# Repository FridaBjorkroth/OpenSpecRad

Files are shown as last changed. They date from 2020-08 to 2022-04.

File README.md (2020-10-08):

# The OpenSpecRad system
This is the repository for files created during the development of an Open-source SpectroRadiometer (OpenSpecRad) system. The OpenSpecRad system is used for in situ measurement of the water-leaving reflectance, used in water quality monitoring of marine and lake water. All software and drawings are available and open-source, which means that anyone can download and use and/or make changes to the construction.

The water-leaving radiance is the spectrum of sunlight backscattered out of the ocean after interaction with the water and its constituents. Each component, as well as the water itself, has different inherent optical properties (IOPs) and absorbs and scatters different parts of the spectrum. Therefore the water-leaving radiance holds quantitative and qualitative information about the main optically active components of water, i.e. chlorophyll-a (Chl-a), coloured dissolved organic
matter (CDOM), and total suspended matter (TSM). Through bio-optical algorithms their concentrations can be derived.

## Using the OpenSpecRad system 
The downwelling irradiance Ed(z,λ) and upwelling radiance Lu(z,λ) is measured using an in-water instrument (Pic), as well as the downwelling irradiance just above the sea surface Ed(0+,λ) using a separate unit. The in-water instrument was built from two 3D-printed pressure and waterproof housings mounted onto a custom steel frame. The above-water unit was put in a plastic box to make it splash-proof. The measurement is started remotely by connecting a laptop/smartphone to the local WiFi network managed by the above-water unit. 

## Hardware
The hardware was based on the STS Developer's Kit from Ocean Optics (now Ocean Insight). The in-water units each include a STS-VIS miniature spectrometer, a Raspberry Pi 3B+ single-board computer, a Bar30 pressure sensor from Blue Robotics coupled via an I²C level converter, and a 10 Ah battery. The above-water unit was configured in the same way, except for the pressure sensor that was swapped for a real-time clock (RTC).

## Software
The open-source spectrometer device driver library SeaBreeze (version 3.0.11, Ocean Optics) was used for communicating with the spectrometers. A C program was written for making spectral measurements. A shell program was then developed for controlling the OpenSpecRad system from a laptop, e.g. starting the measurement programs, detecting errors, and transferring the collected data remotely via SSH. The measurement parameters, e.g. integration time, minimum depth for the first measurement, and depth resolution, were read from separate files when starting the three radiometric acquisitions, making changes of parameters easy.





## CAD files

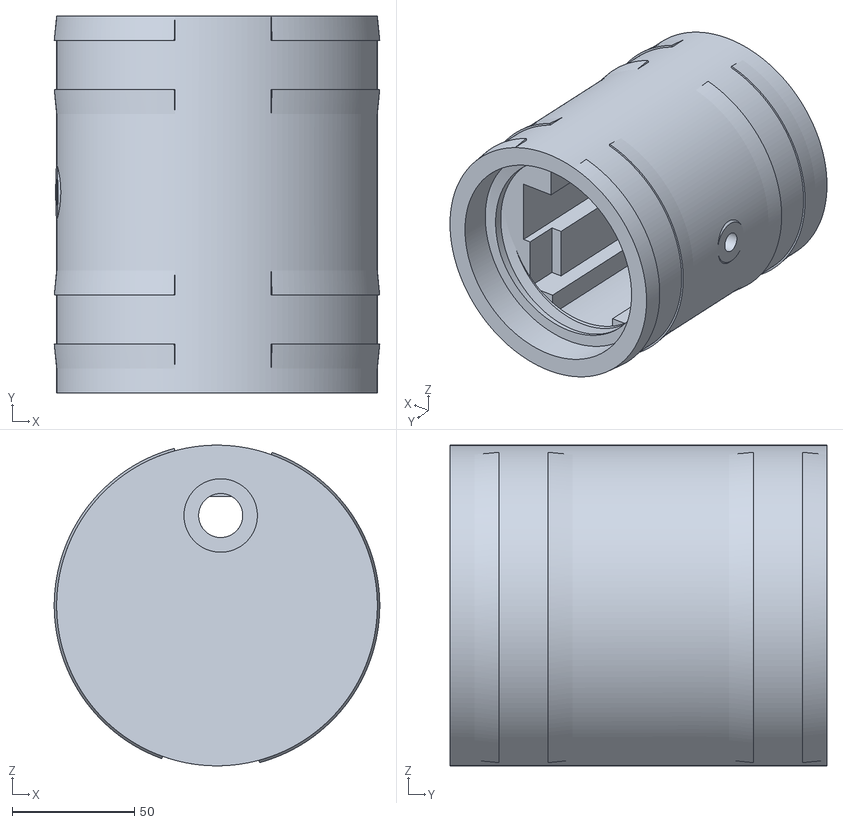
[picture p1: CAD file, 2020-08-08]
Housing and frame/Housing_11052020.stl
133.0 x 154.0 x 131.0

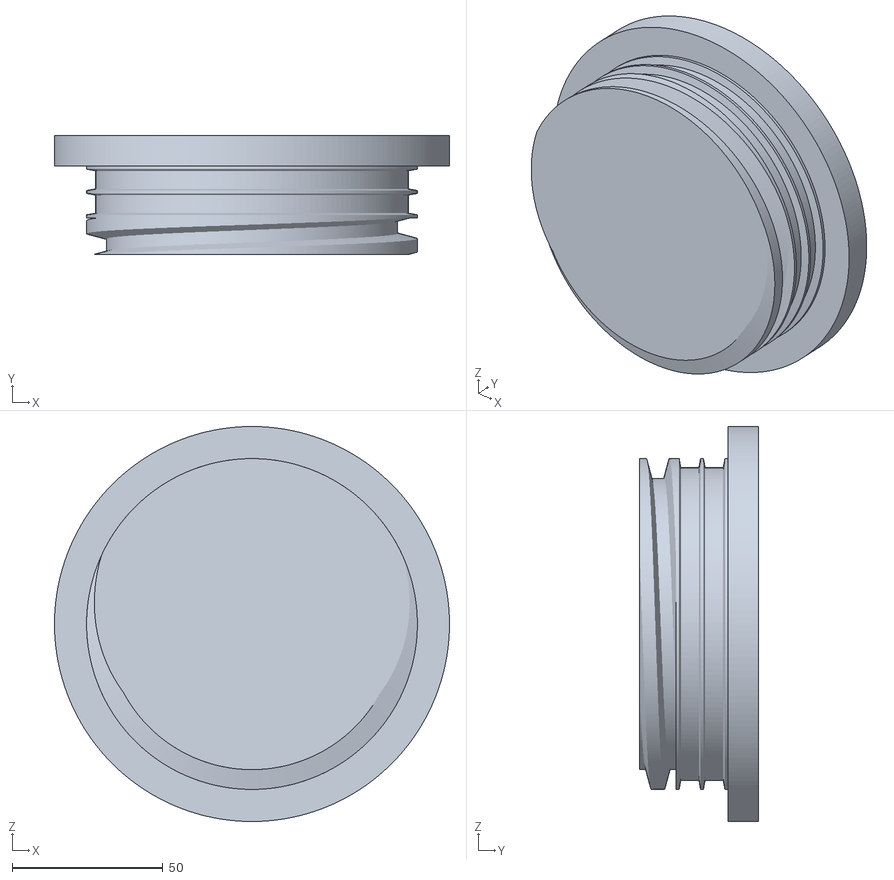
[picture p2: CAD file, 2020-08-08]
Housing and frame/Lid_11052020.stl
131.0 x 39.3 x 131.0

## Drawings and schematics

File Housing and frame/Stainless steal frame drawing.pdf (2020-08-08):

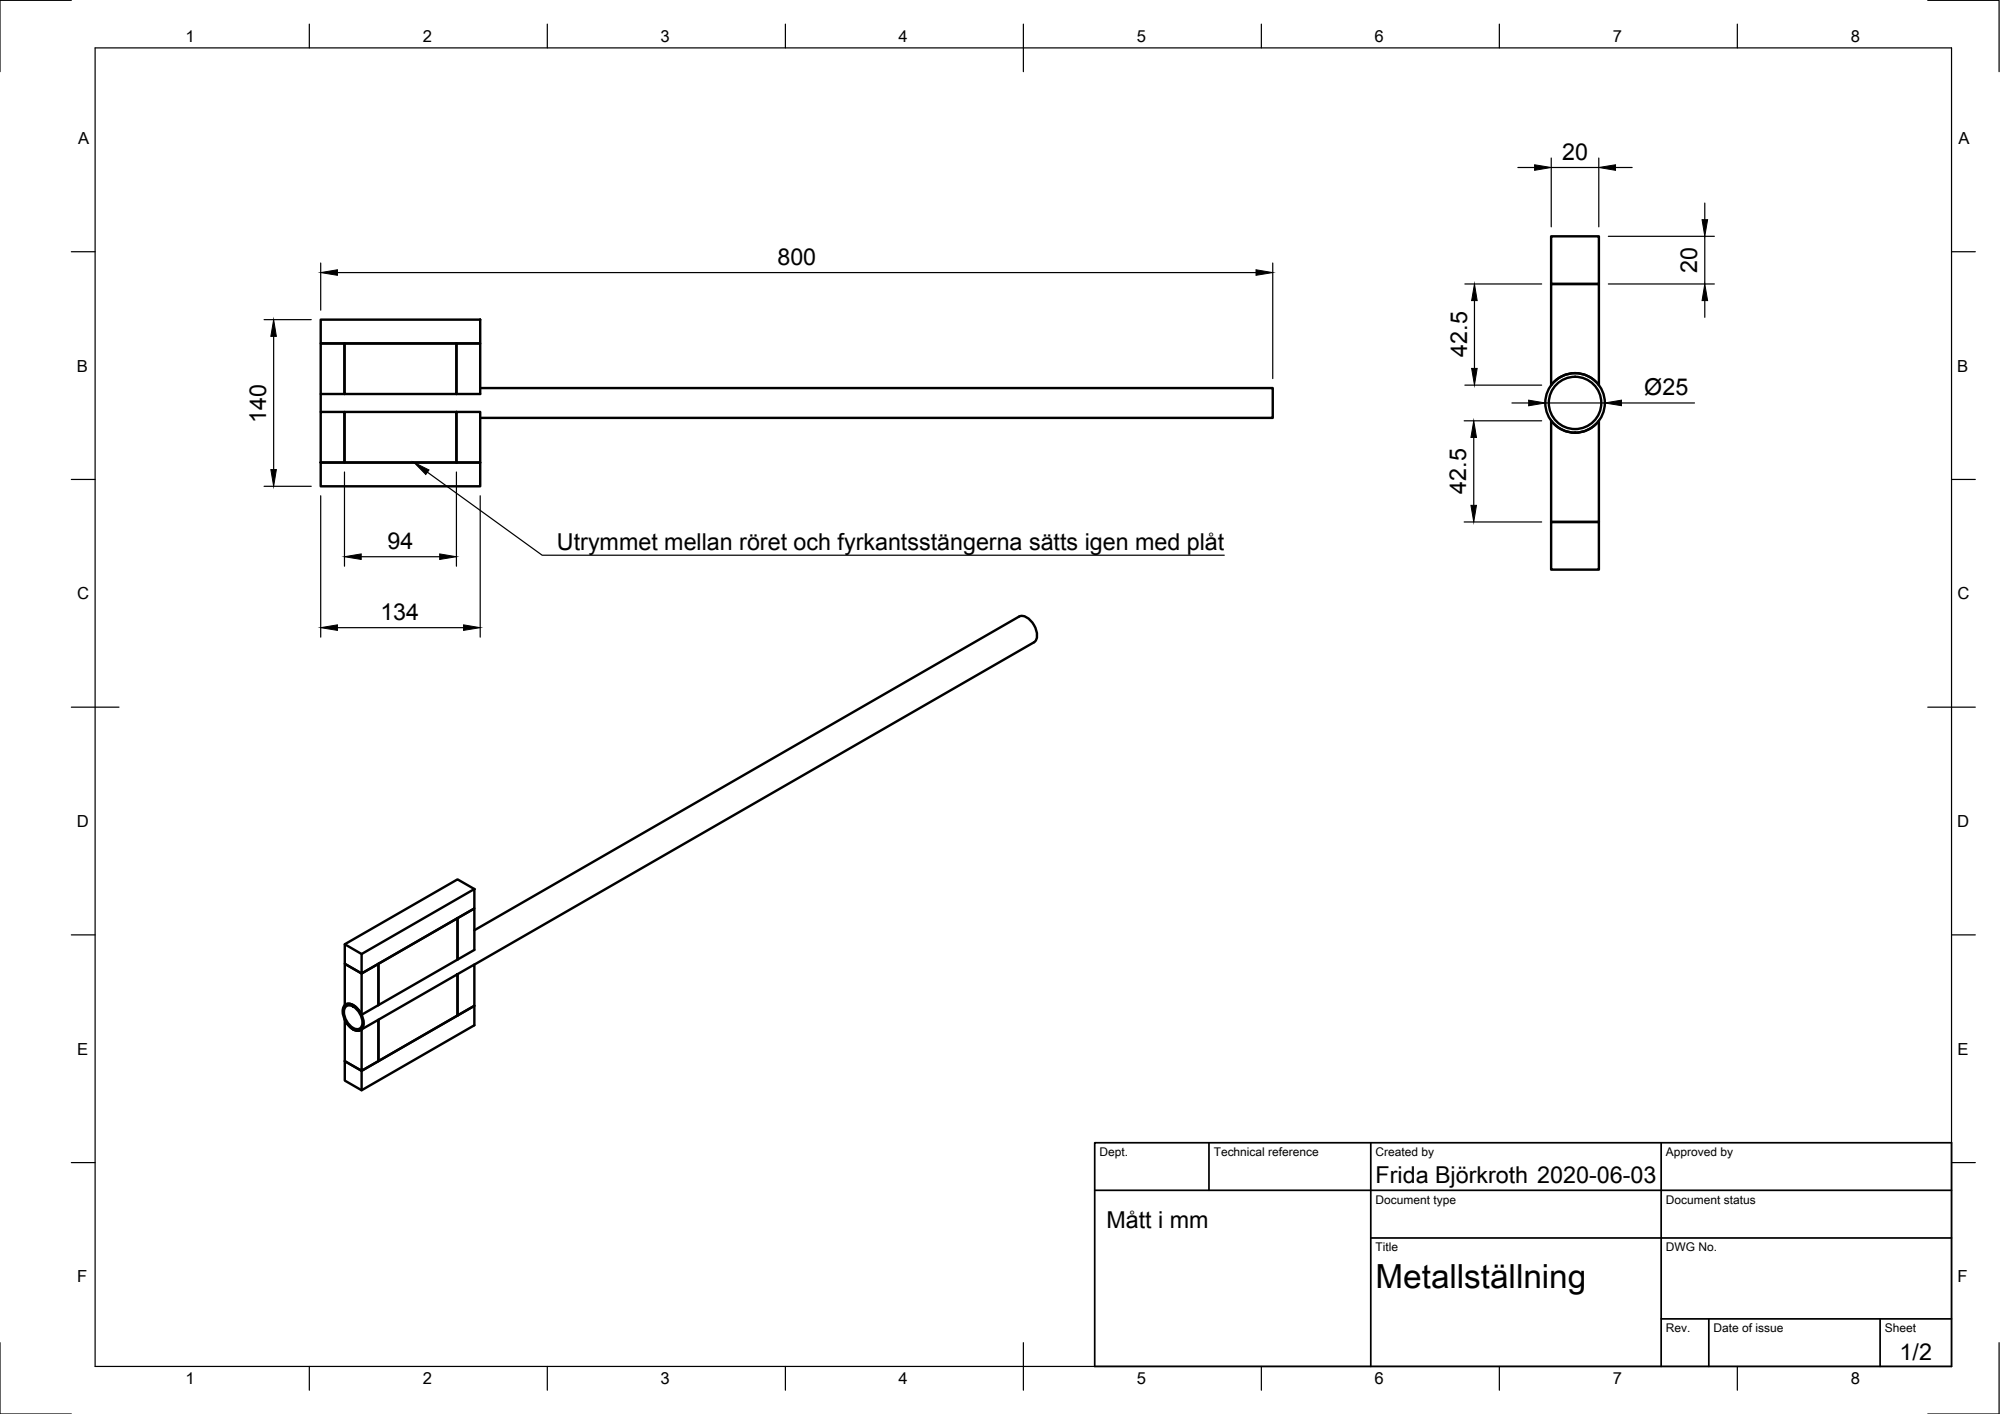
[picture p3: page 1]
Frida Björkroth; Utrymmet mellan röret och fyrkantsstängerna sätts igen med plåt

Dept. | Technical reference | Created by 2020-06-03 | Approved by

Mått i mm | | Document type | Document status

Title Metallställning | DWG No.

Rev. | Date of issue | Sheet 1/2

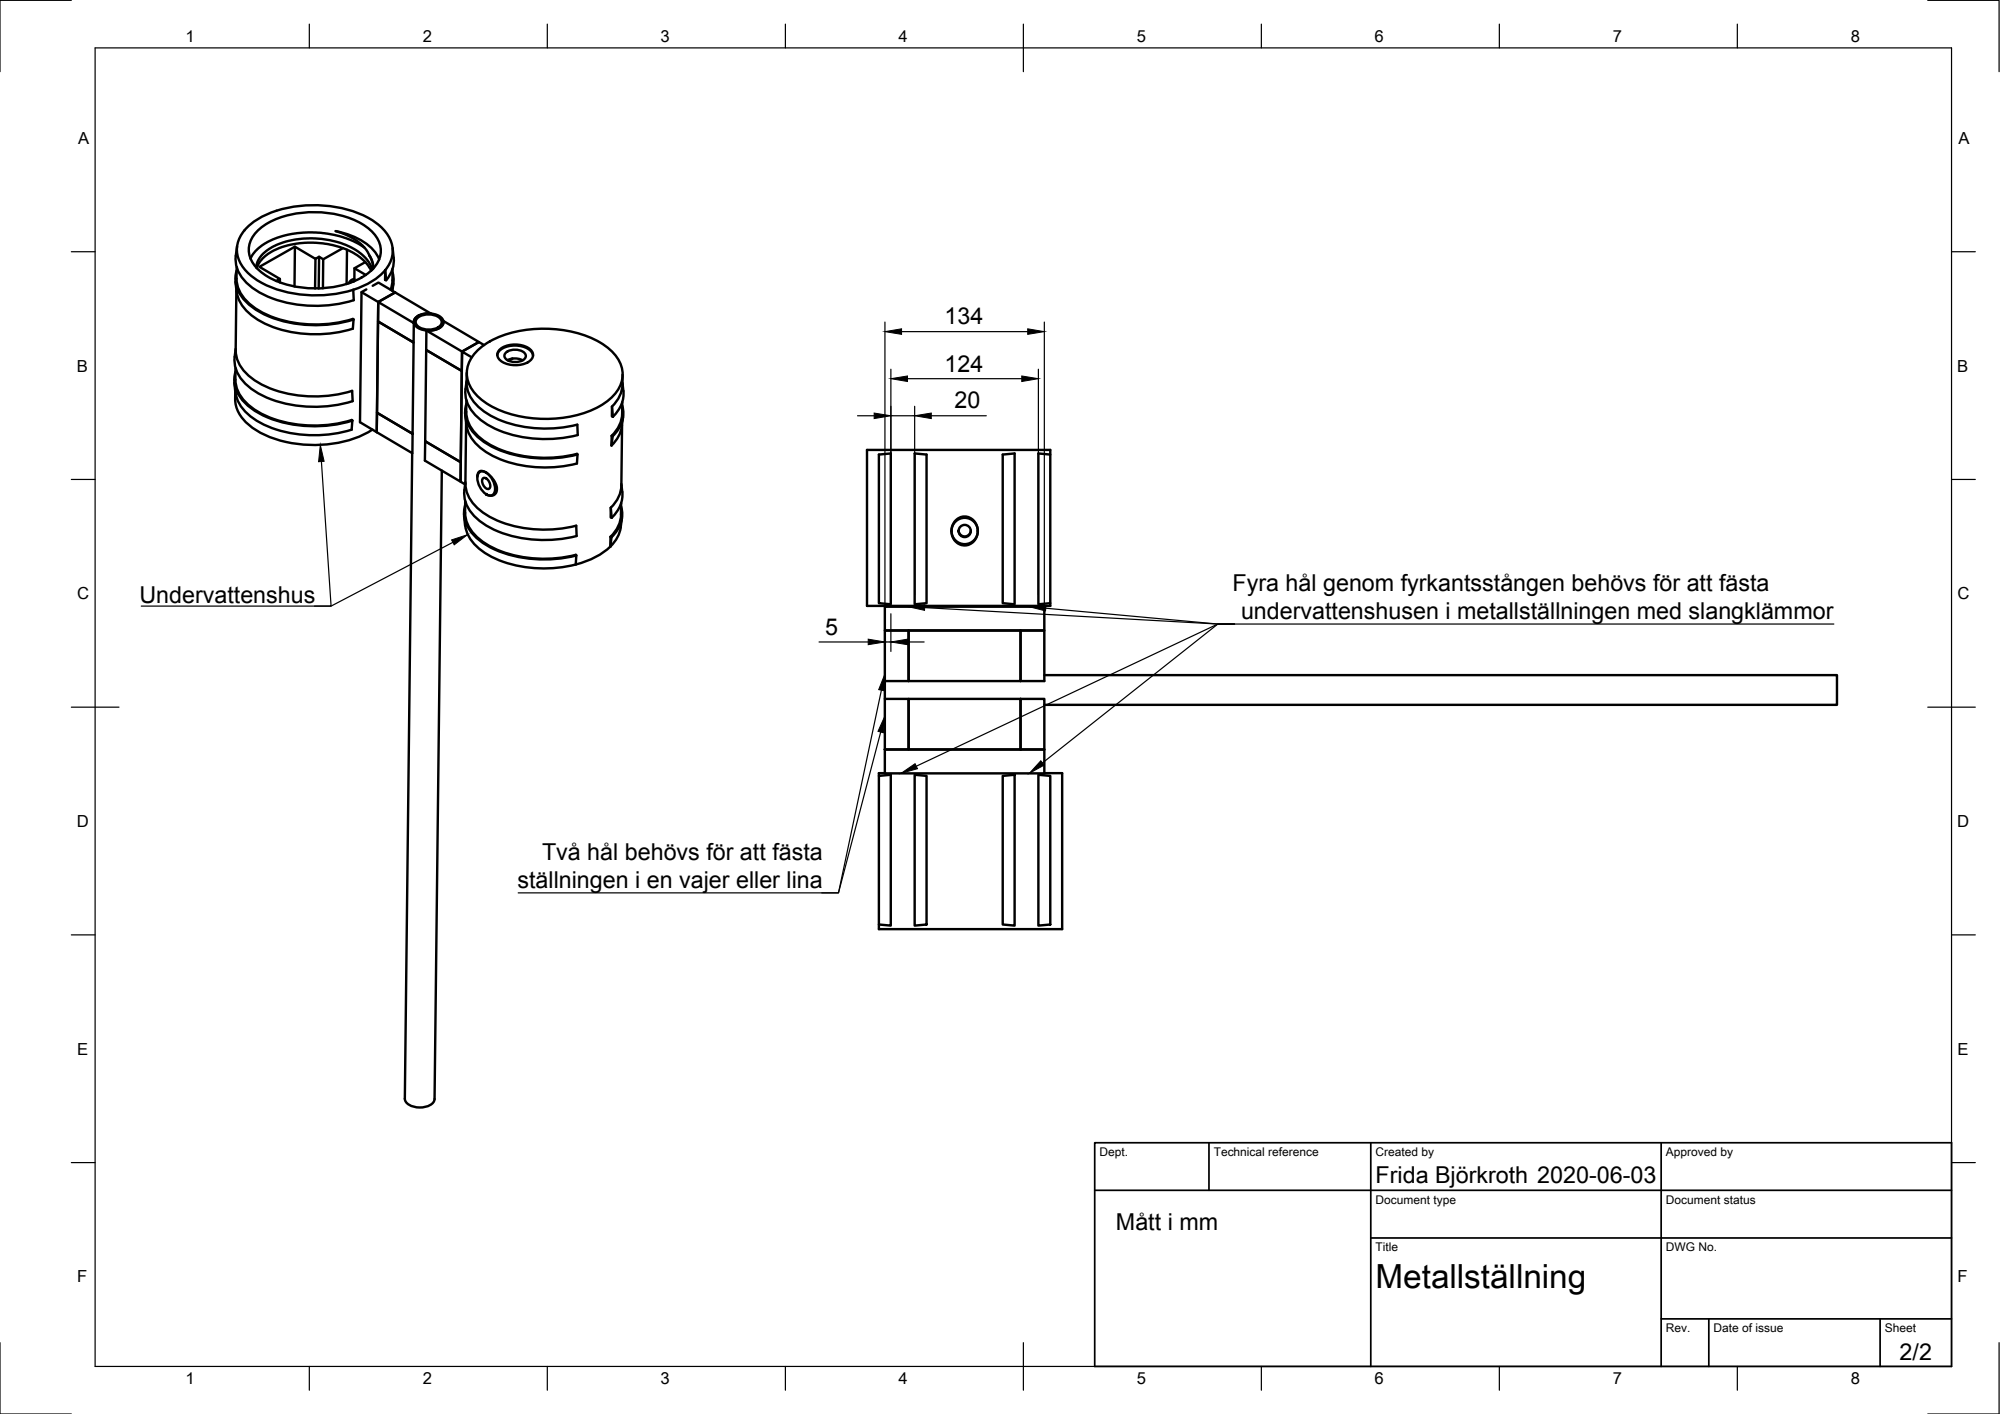
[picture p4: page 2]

Fyra hål genom fyrkantsstången behövs för att fästa

undervattenshusen i metallställningen med slangklämmor Undervattenshus

Två hål behövs för att fästa
ställningen i en vajer eller lina

Dept. | Technical reference | Created by Frida Björkroth 2020-06-03 | Approved by

Mått i mm | | Document type | Document status

Title Metallställning | DWG No.

Rev. | Date of issue | Sheet 2/2

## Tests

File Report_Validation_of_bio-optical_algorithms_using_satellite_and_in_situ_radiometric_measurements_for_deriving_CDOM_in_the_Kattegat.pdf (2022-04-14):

## DEPARTMENT OF MARINE SCIENCES

# VALIDATION OF BIO-OPTICAL ALGORITHMS USING SATELLITE AND IN SITU RADIOMETRIC MEASUREMENTS FOR DERIVING COLOURED DISSOLVED ORGANIC MATTER (CDOM) IN THE KATTEGAT

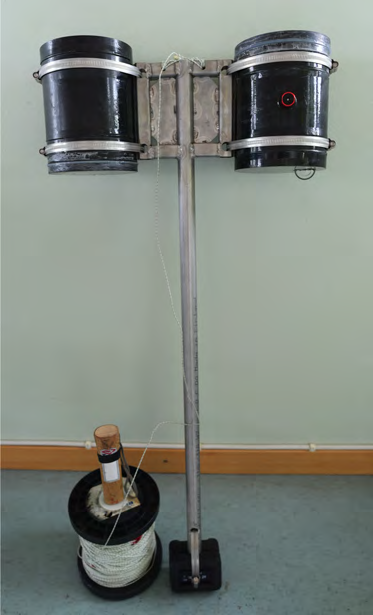
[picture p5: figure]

Figure 1: The in-water instrument, part of the

in situ Open-source SpectroRadiometer (Open-

SpecRad) system.

Frida Björkroth

Degree project for Master of Science (120 hp) with a major in Marine Sciences MAR703, Exam course for Master’s degree in Marine Science - Chemistry, 60 hp Second Cycle
Semester/year: Spring 2020
Supervisor: Martin Hassellöv, Department of Marine Sciences
Examiner: Katarina Abrahamsson, Department of Marine Sciences

## Validering av bio-optiska algoritmer för beräkning av

## humusämnen i Kattegatt

Satellitbaserad fjärranalys av havsfärg innebär att mäta solljuset som spridits tillbaka upp från

havsvattnet efter att ha interagerat med vattnet och dess innehåll. De huvudsakliga optiskt

aktiva beståndsdelarna, klorofyll-a, humusämnen och lösta partiklar, har olika egenskaper

som påverkar vilka färger (våglängder) av ljuset som absorberas eller sprids. Därför innehåller

ljuset information om mängd och om vilka av beståndsdelarna som finns där. Intresset för

humusämnen har nyligen ökat, eftersom man vill uppskatta det globalt lösta kolet i havet för

bättre förståelse av kolcykeln. Mätning av löst kol är tidskrävande och kostsamt, så därför

kan humusämnen användas för att uppskatta kolmängden. Humusämnen absorberar blått ljus

och ser därför gula ut i vatten. Genom bio-optiska algoritmer, som kopplar ihop biologiska

och optiska egenskaper, kan mängden av beståndsdelarna beräknas från satellitmätningar av

ljuset. De globala algoritmerna som används idag fungerar bra i optiskt enkla vatten, där

klorofyll-a dominerar, men misslyckas i optiskt komplicerade vatten, där humusämnen och

lösta partiklar dominerar. Därför har enkla regionala algoritmer som baseras på förhållandet

mellan två olika våglängdsband utvecklats.

En av de senaste sensorerna för fjärranalys av havsfärg är Ocean and Land Color Instrument

(OLCI) ombord på satelliterna Sentinel-3A och 3B. Dess våglängdsband är speciellt utvalda för

övervakning av optiskt komplicerade kustvatten. Validering och uppskattning av osäkerheter

från olika vattenmiljöer är avgörande för tillförlitlig data från OLCI. Detta görs genom

jämförelse mellan sammanfallande satellitmätningar och mätningar på plats i eller precis

ovanför vattnet. Dock har aldrig ljusmätningarna från OLCI med fokus på humusämnen

validerats omfattande i Kattegatt. Därför jämfördes mätningar av humusämnen på plats

i Kattegatt med lokalt anpassade algoritmer applicerade på mätningar från ett egenbyggt

optiskt instrument (Open-source SpectroRadiometer system, OpenSpecRad) och OLCI satel-

litmätningar. Resultaten visar att mängden humusämnen förutspått av algoritmerna inte

hade något förhållande till den verkliga mängden humusämnen, på grund av stor tidsskillnad

mellan satellitmätning och mätning på plats i lokala anpassningen av algoritmerna, orsakat

av molntäcke. För första gången visas det att OLCI-dataprodukten för färgat detritus och

löst material, ADG443, inte hade något förhållande till mätningar av humusämnen på plats.

Molntäcken är den största svagheten med satellitbaserad fjärranalys i Kattegatt, liksom

i resten av norra Europa. ADG443 rekommenderas inte att användas för att uppskatta

mängden humusämnen i Kattegatt. I framtiden skulle satellitbaserad fjärranalys av havsfärg

kunna öka tillgängligheten av mätningar av humusämnen och användas i övervakning av

vattenkvalitet. OpenSpecRad är billig och fritt tillgänglig för vem som helst att bygga, vilket

utmanar gränserna för vem som kan bidra till vetenskapen.

## Abstract

Satellite remote sensing of ocean color involves deriving the water-leaving radiance (Lw), which

is the spectrum of sunlight backscattered out of the ocean after interaction with the water

and its constituents. The Lw holds quantitative and qualitative information about the main

optically active components of seawater, i.e. chlorophyll-a (Chl-a), coloured dissolved organic

matter (CDOM), and total suspended matter (TSM). The interest in CDOM has recently

increased due to the estimation of the global dissolved organic carbon (DOC) pool for the

understanding of the changing carbon cycle. The global bio-optical algorithms and processors

deriving water quality components from Lw perform well in optically simple Case-1 waters,

dominated by Chl-a, but they fail in Case-2 waters, dominated by CDOM and TSM. Therefore,

regional empirical algorithms, which depend on the ratio of two water-leaving reflectances

(ρw) (derived from Lw) at different wavelengths, have been developed for determination of the

absorbance coefficient for CDOM at wavelength 443 nm, aCDOM (443). However, there has

been no considerable validation of the data from the new Ocean and Land Colour Instrument

(OLCI) onboard the Sentinel-3 satellites nor regional empirical algorithms in the Kattegat.

This study shows that aCDOM (443) predicted by the local algorithms has no correlation

with in situ data, due to the large time difference between satellite overpass and in situ

measurements in the local fitting of algorithms caused by cloud coverage. For the first time,

it is also shown that the OLCI product for coloured detritus and dissolved matter, ADG443,

has no correlation with aCDOM (443) in the Kattegat. Here, a self-built in situ Open-Source

SpectroRadiometer (OpenSpecRad) system is also developed. The cloud coverage is the

main weakness of satellite remote sensing in the Kattegat, as well as in northern Europe.

Further, the ADG443 product is not recommended for using as a proxy for aCDOM (443) in

the Kattegat. In the future, satellite remote sensing in the Kattegat could immensely increase

the data availability for CDOM estimation and be used in water quality monitoring. The

OpenSpecRad system is low-cost and free for anyone to build, hence pushing the limits for

who can contribute to science.

## Contents

1 Introduction | 1
2 Materials and Method | 18
3 Result and Discussion | 23
4 Conclusion | 30
Acknowledgements | 31
References | 31
Appendix A Building the OpenSpecRad | 38

## Symbols and Abbreviations

Symbol | Unit | Description

0

− | m | Just under the sea surface

0

+ | m | Just above the sea surface
A | m² | Spherical surface area
a | m⁻¹ | Absorption coefficient
B | unit-less | Function used in self-shading correction, depends on wavelength and
| | sun zenith angle
b | m⁻¹ | Total scattering coefficient
bb | m⁻¹ | Backscattering coefficient
β(θ) | m⁻¹
| sr⁻¹ | Volume scattering function
Cs | | Coefficient describing variation in Sun-Earth distance
E | W m⁻³ | Irradiance
Ed | W m⁻³ | Downwelling irradiance
Eu | W m⁻³ | Upwelling irradiance
| | Error
F0 | W m⁻³ | Mean solar spectral irradiance at the top of the atmosphere
Fi | unit-less | Immersion correction factor
f | unit-less | Self-shading correction factor
Kd | m⁻¹ | Diffuse attenuation coefficient of downwelling irradiance
Kl | m⁻¹ | Diffuse attenuation coefficient of upwelling radiance
KP | m⁻¹ | Diffuse attenuation coefficient, i.e Kl(λ), Kd(λ) and Ku(λ) calculated
| | from Lu(z, λ), Ed(z, λ) and Eu(z, λ), respectively
Ku | m⁻¹ | Diffuse attenuation coefficient of upwelling irradiance
L | W sr⁻¹ m⁻³ | Radiance
Li | W sr⁻¹ m⁻³ | Sky radiance
LT | W sr⁻¹ m⁻³ | Total radiance emerging from sea surface
Lu | W sr⁻¹ m⁻³ | Upwelling radiance
Lw | W sr⁻¹ m⁻³ | Water-leaving radiance
Lwn | W sr⁻¹ m⁻³ | Normalized water-leaving radiance
λ | nm | Wavelength

µs

- Cosine of the solar zenith angle
ng, nw | unit-less | Refractive indices of glass window and seawater, respectively
Ω | sr | Solid angle
∆Φ | ◦ | Difference between sun and sensor azimuth angle
P | | Radiometric parameters (Lu, Ed or Eu)
Q, Qn | | Q-factors describing anisotropy (dependency of direction)

<, <0 | | Describing sea surface reflectance and refraction
Rrs | sr⁻¹ | Remote sensing reflectance
r | m | Radius
ρw | unit-less | Water-leaving reflectance
t, t0 | | Time and start time, respectively
tdown | unit-less | Downward transmittance of the atmosphere
τa | unit-less | Aerosol optical thickness

θ

0 | ◦ | Angle from zenith

θ0

- Sun zenith angle

θ

- Angle from nadir
W | ms⁻¹ | Windspeed
z | m | Depth
Abbreviation | Description
ADG443 | OLCI satellite-derived absorption of coloured detritus and dissolved
| matter at 443 nm
AC | Atmospheric correction
AAC | Alternative atmospheric correction
ABS | Acrylonitrile butadiene stryrene
AOP | Apparent optical property
APD | Average percentage difference
API | Application programming interface
BAC | Baseline atmospheric correction
C2RCC | Case-2 Regional CoastColour algorithm
CAD | Computer-aided design
CCD | Charge-coupled device
CDOM | Coloured dissolved organic matter
Chl-a | Chlorophyll-a
CZCS | Coastal Zone Color Sensor
DC | Digital counts
ESA | European Space Agency
EUMETSAT | European Organisation for the Exploitation of Meteorological Satellites
FAFOV | Full-angle field-of-view

I

2C | Inter-integrated circuit
IDE | Integrated development environment
IOP | Inherent optical property
IP | Internet protocol

L0, L1, L2 | Level 0, Level 1, Level 2
MERIS | Medium Resolution Imaging Spectrometer
MNB | Mean normalized bias
MODIS | Moderate Resolution Imaging Spectrometer
NOOBS | New Out Of Box Software
NRT | Near real-time
NTC | Non-time critical
OC4ME | Ocean Colour for MERIS algorithm
OLCI | Ocean and Land Colour Instrument
OpenSpecRad | Open-source Spectroradiometer
PLA | Polylactic acid
RMSE | Root mean square error
RPi | Raspberry Pi
RTC | Real-time clock
s | Standard deviation
SD | Secure digital
SeaWiFS | Sea-viewing Wide Field-of-view Sensor
SSH | Secure shell
TOA | Top-of-atmosphere
TSM | Total suspended matter
UAVs | Unmanned aerial vehicles

## 1 Introduction

Satellite remote sensing of ocean colour involves deriving the water-leaving radiance (Lw),

which is the spectrum of sunlight backscattered out of the ocean after interaction with the

water and its constituents (Groom et al., 2019). In the coastal ocean, the main optically

significant components determining the ocean colour are chlorophyll-a (Chl-a), coloured

dissolved organic matter (CDOM), and total suspended matter (TSM) (Koponen et al., 2007;

Kratzer et al., 2014). Each component, as well as the water itself, has different inherent

optical properties (IOPs) and absorbs and scatters different parts of the spectrum (Kyryliuk,

2019). Therefore, the Lw contains quantitative and qualitative information about the in-water

constituents (Loisel et al., 2013). Their concentrations are derived using so-called bio-optical

algorithms which are based on their IOPs (Kratzer and Moore, 2018).

Today, the global bio-optical algorithms and standard processors deriving water quality

products perform well in optically simple open ocean (Case-1) waters, where the IOPs are

dominated by Chl-a, but they fail in optically complex coastal and partially enclosed marine

(Case-2) waters, dominated by CDOM and TSM (Kowalczuk et al., 2005; Matsushita et al.,

2012; Seelye, 2014). Therefore, regional empirical and semi-analytical algorithms have been

developed and evaluated for the determination of water quality products, e.g. in the Baltic

Sea (Kowalczuk et al., 2010; Ligi et al., 2017; Toming et al., 2017). The empirical algorithms,

also called band-ratio algorithms, only depend on the ratio of two water-leaving reflectances

ρw (derived from Lw) at different wavelengths and therefore they are computationally fast

and widely used (Ligi et al., 2017; Seelye, 2014).

The interest in CDOM, also known as gelbstoff, humic substance, yellow substance, or

chromophoric dissolved organic matter, has recently increased, due to the current estimation

of the global dissolved organic carbon (DOC) pool for the understanding of the carbon cycle

under change (Koponen et al., 2007; Kowalczuk et al., 2010; Tian et al., 2012). CDOM is the

optically active fraction of DOC and since DOC measurements are costly and time-consuming

CDOM is often used as a proxy (Harvey et al., 2015; Kowalczuk et al., 2010; Mishra et al.,

2017). In addition, CDOM plays a key role for a better understanding of the air-sea exchange

of inorganic carbon species (CO, CO2 and COS), the formation of reactive oxygen species, its

impact on satellite remote sensing of primary production, and attenuation of ultraviolet light in surface waters (Kowalczuk et al., 2010).

CDOM is dominated by humic and fulvic acids which originates from the degradation of

terrestrial and aquatic plant matter and is primarily transported into coastal waters through

rivers and estuaries (Seelye, 2014; Stedmon et al., 2003, 2010). Hence, the CDOM concentration

is inversely related to the salinity (Højerslev et al., 1996). CDOM is ubiquitous in natural

waters and has aromatic, carboxylic acid, and phenolic groups, shaping its optical signature

(Brezonik et al., 2005). CDOM is optically characterized by its absorption coefficient (aCDOM )

and is primarily absorbing light in the ultraviolet (UV) and the blue regions (450-490 nm)

of the spectrum (Bricaud et al., 1981). Its absorption decreases with increasing wavelength

according to the exponential equation (Bricaud et al., 1981)

aCDOM (λ) = aCDOM (λ0)e

−S(λ−λ0)
(1)

where aCDOM is the absorption coefficient at wavelength λ, λ0 is the reference wavelength,

and S is the slope factor (Kowalczuk et al., 2010).

Ocean colour was monitored for the first time by satellite remote sensing when the Coastal

Zone Color Sensor (CZCS) was launched in 1978, proving the concept of measuring ocean

productivity from space (Groom et al., 2019; Kyryliuk and Kratzer, 2019). The following

decades several one-off sensors were launched, e.g. the Sea-viewing Wide Field-of-view Sensor

(SeaWiFS), the Moderate Resolution Imaging Spectrometer (MODIS), and the Medium

Resolution Imaging Spectrometer (MERIS) (Berthon et al., 2008). One of the most recent

sensors, the Ocean and Land Colour Instrument (OLCI) on the Sentinel-3A and Sentinel-3B

satellites is part of the Sentinel-3 mission led by the European Space Agency (ESA) and

the European Organisation for the Exploitation of Meteorological Satellites (EUMETSAT)

(Groom et al., 2019). The OLCI spectral configuration is especially designed for monitoring of

coastal Case-2 waters (Donlon et al., 2012; Toming et al., 2017). The Sentinel-3 mission marks

the beginning of consistent ocean colour observations of coastal waters in the following decades.

However, validation and determination of uncertainties from different aquatic environments

are crucial for reliable OLCI ρw and water quality products (Toming et al., 2017; Zibordi

et al., 2012). This is performed by comparison of satellite products with in situ reference

measurements (Zibordi et al., 2012).

The Kattegat Sea is part of the transition zone between the Baltic Sea and the North Sea.

Its water originates from three different water masses, (1) low-salinity (8 PSU) Baltic Sea

water with high aCDOM , (2) high-salinity (35 PSU) North Sea water with low aCDOM and

(3) high-salinity (31 PSU) German Bight water with high aCDOM (Højerslev et al., 1996;

Stedmon et al., 2010). The Kattegat Sea bottom water is a mix of North Sea water (90%) and

German bight water (10%) while the surface water is dominated by the Baltic Sea water, which

flows northward along the Swedish coast (Björk and Nordberg, 2003; Højerslev et al., 1996).

Previous CDOM studies in the Kattegat have been focusing on water mass mixing (Stedmon

et al., 2010) and characterization of components (Osburn and Stedmon, 2011; Persson and

Wedborg, 2001; Stedmon et al., 2003). Sørensen et al. (2007) performed a validation of MERIS

data in the Skagerrak, with some sampling stations in the Kattegat. Although, there has

been no extensive validation of the OLCI data products including CDOM in the Kattegat.

Therefore, the aim of this study is to investigate the potentials of radiometric measurements

and published bio-optical algorithms for water quality monitoring in the Kattegat with the

focus on CDOM, using data from the Sentinel-3 OLCI satellites and a self-built in situ

Open-source SpectroRadiometer (OpenSpecRad) system. Hence, this study also aims to build

a low-cost in situ spectroradiometer system and can thereby be used as a handbook.

### 1.1 Inherent and Apparent Optical Properties

The inherent optical properties (IOPs) of seawater, i.e. the absorption coefficient (a), the

scattering coefficient (b), and the volume scattering function (β(θ)), only depend on the

nature of the medium and are independent of the ambient light field (Kratzer et al., 2017;

Preisendorfer, 1961). The intensity of light underwater reduces with increasing depth due to

the absorption and scattering of the in-water components (Kratzer et al., 2014).

CDOM absorbs light predominantly in the blue (450-490 nm) part of the spectrum, whereas

Chl-a absorbs light both in the blue and red (635-700 nm) part (Kratzer et al., 2014). TSM

mainly scatters light, which means a photon changes its direction after interaction with the

matter (Kratzer et al., 2014, 2017). Backscattered photons are photons that are reflected at

angles less than 90◦ or π/2 radians.

For a given water body the absorption coefficient (a) of light can be described as

a(λ) = aw(λ) + aChl−a(λ) + aCDOM (λ) +aT SM (λ), | (2)

the total scattering coefficient (b) of light as

b(λ) = bw(λ) + bT SM (λ), | (3)

and the backscattering coefficient (bb) of light as

bb(λ) = bbw(λ) + bbT SM (λ) | (4)

where λ is the wavelength and the subscripts w refers to clear water, Chl-a to chlorophyll-a,

CDOM to coloured dissolved organic matter, and TSM to total suspended matter (Kratzer

and Moore, 2018; Seelye, 2014).

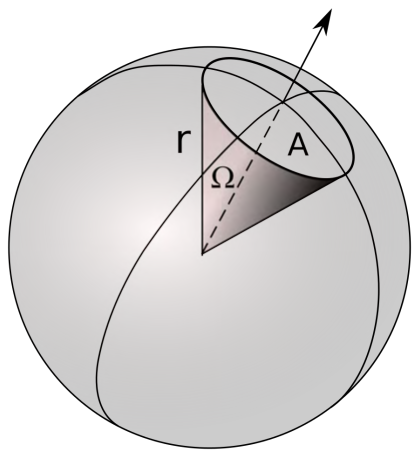
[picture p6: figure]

Figure 2: The solid angle (Ω) defined by the spherical surface

area A and the radius of the sphere r, according to equation

5.

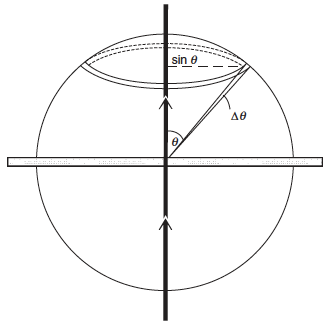
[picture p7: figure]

Figure 3: The differential solid angle (d Ω) of a light beam,

defined by the scattering angles θ to θ + ∆θ with radius sin(θ),

according to equation 6. Adopted from Kirk (2011).

Because particle scattering is directionally dependent, it is characterized by the volume

scattering function (β(θ)) (Kratzer and Moore, 2018). It describes how a given volume of

water scatters incident light into different directions in a three-dimensional space. Firstly, the

equivalent of the two-dimensional planar angle in a three-dimensional space is called the solid

angle (Ω) (Fig. 2). It is the angular volume, often a cone, created by lines from a patch of area on a sphere meeting at the centered apex and is defined as

Ω = A
r

2

(5)

where A is the spherical surface area and r is the radius of the sphere (Seelye, 2014). The

solid angle has unit steradian (sr), with 4π sr in a sphere, since the surface area of a sphere is

A = 4πr²
(Seelye, 2014). Secondly, the differential solid angle (d Ω) can be explained as a

light beam passing through a medium and is scattered between angle θ and θ + ∆θ, enclosing

an area with radius sin(θ) according to

dΩ = 2π sin(θ) dθ | (6)

(Fig. 3) (Kirk, 2011).

Thereby, the b(λ) is the integral of the β(θ,λ) over all Ω, according to

b(λ) = Z

4π

β(θ,λ) dΩ | (7)

(Mobley, 1995). Combining equation 6 and 7 gives

b(λ) = 2π

Z π

0

β(θ,λ) sin(θ) dθ | (8)

where 0 ≤ θ ≤ π radians denote all directions. This means the bb(λ) is the integral over the

backwards direction π/2 ≤ θ ≤ π radians as

bb(λ) = 2π

Z π

π/2

β(θ,λ) sin(θ) dθ | (9)

(Mobley, 1995). Backscattering is a crucial part of ocean optics since most of the light emerging

upwards from the ocean is originally downward directed sunlight, which was redirected upwards

(Kratzer et al., 2017). Together the absorption and backscattering form the colour of the

oceans.

The CDOM absorption coefficient, aCDOM (λ), is derived using (Kirk, 2011; Kratzer and

Moore, 2018):

aCDOM (λ) = ln(10)A(λ) /l | (10)

where A is the absorbance and l is the cuvette path length in cm. The aCDOM is often

calculated at wavelengths 412 or 420-443 nm (Brezonik et al., 2015).

In contrast to the IOPs, the apparent optical properties (AOPs) of seawater are both dependent

on the medium and the ambient light field (Preisendorfer, 1961). The light field is quantified

by the radiance (L) and the irradiance (E). Irradiance is how much light that hits a specified

area and has unit watt per square meter per meter (W m⁻³

), more often as mW cm⁻² nm⁻¹

(Kirk, 2011; Zibordi et al., 2012). Radiance is how much light coming through a specified

area and falling into a given solid angle in a defined direction and has unit watt per steradian

per square meter per meter (W sr⁻¹ m⁻³

), often expressed as mW sr⁻¹

cm⁻² nm⁻¹
(Kratzer

et al., 2017; Zibordi et al., 2012). One important AOP is the remote sensing reflectance

Rrs(λ). It is defined as the ratio of water-leaving radiance Lw(λ) to downwelling irradiance

Ed(λ),
Rrs(λ) = Lw(λ) Ed(0⁺,λ)
(11)

where 0

+ is just above the sea surface (Kowalczuk et al., 2005; Zibordi et al., 2012). Both

Lw(λ) and Ed(0⁺,λ) are dependent on the illumination condition, e.g. sun elevation, clouds

and atmospheric conditions, at the moment of measurement (Kratzer et al., 2017). Therefore,

Rrs(λ) is very useful since it is less sensitive to changes in sunlight. Rrs is also proportional

to the absorption coefficient (a) and backscattering coefficient (bb) according to

Rrs ∝

bb
a+bb

(12)

(Kyryliuk, 2019).

Another common AOP is the diffuse attenuation coefficient of downwelling irradiance Kd(z,λ),

which is derived from the exponential decrease in Ed(z,λ) with increasing depth (Eq. 13 and

14) (Kirk, 2011; Kratzer et al., 2017).

Ed(z,λ) = Ed(0⁻,λ) · e

−Kd(λ)· z
(13)

Kd(z,λ) =

−

ln Ed(z,λ) − ln Ed(0⁻,λ)

z

(14)

where z is the depth and 0

− is just below the sea surface (Kirk, 2011).
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

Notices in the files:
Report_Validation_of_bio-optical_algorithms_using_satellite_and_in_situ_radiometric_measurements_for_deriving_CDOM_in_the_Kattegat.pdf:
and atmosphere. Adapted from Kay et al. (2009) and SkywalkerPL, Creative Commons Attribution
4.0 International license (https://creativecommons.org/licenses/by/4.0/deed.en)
